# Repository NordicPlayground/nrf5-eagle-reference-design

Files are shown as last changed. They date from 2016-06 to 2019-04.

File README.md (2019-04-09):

# Nordic semiconductor eagle reference design

## Reference designs
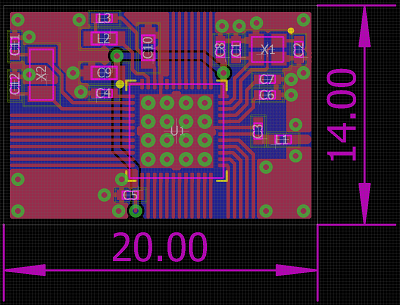
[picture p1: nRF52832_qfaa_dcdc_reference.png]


The reference designs supplied for eagle are made by following the [general pcb design guidelines][designguidenrf52] and referencing the [altium reference layout][altiumreference].
The eagle reference design is not the official reference designs, only the Altium reference designs has been tested and verified. They are available for download in Nordic's product pages.
The reference designs include eagle files as well as pdf printouts. For BOM see the altium reference designs.

* nRF51x22_qfaa
* nRF51x22_qfaa_dcdc
* nRF52832_qfaa
* nRF52832_qfaa_dcdc
* nRF52832_qfaa_nfc

## Libraries
**The libraries are not verified, only the Altium reference designs has been tested and verified.**

### Nordic_nRF
This library contains the nRF51 and nRF52 in qfn and bga packages, as well as; capacitors, inductors, and a 32MHz and 32kHz xtal. All that is needed for the core reference design. (link?)

### Nordic_misc
This library contains the rest of the components used in the sample eagle design(s) in this repository, as well as some simple antenna suggestions.

## Antenna
In the Nordic_misc library there is supplied some suggestions for antennas, please note that antenna characteristics depends greatly on the board layout. These antennas are made according to the [whitepaper][monopole] on quarter wave monopole 2.45 GHz antennas. Remember to [tune][antuning] the antenna

## NFC
An NFC listener antenna suggestion is supplied in the Nordic_misc library, this is the antenna used in the [nRF52-DK] development kit. Remember to [tune][nfctune] the antenna.

[github]: <https://github.com/NordicPlayground/nrf5-eagle-reference-design>
[designguidenrf51]: <https://devzone.nordicsemi.com/blogs/655/general-pcb-design-guidelines-for-nrf51/>
[designguidenrf52]: <https://devzone.nordicsemi.com/blogs/870/general-pcb-design-guidelines-for-nrf52/>
[referencecircuitry]: <https://infocenter.nordicsemi.com/index.jsp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>
[altiumreference]: <http://infocenter.nordicsemi.com/index.jsp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>
[nfctune]: <https://devzone.nordicsemi.com/blogs/957/nfc-tag-antenna-tuning/>
[nRF52-DK]: <http://www.nordicsemi.com/eng/Products/Bluetooth-low-energy2/nRF52-DK>
[dcdc_reference]: <nRF52832_qfaa_dcdc_reference.png>
[monopole]: <http://infocenter.nordicsemi.com/topic/com.nordic.infocenter.whitepapers/dita/whitepapers/pdflinks/nwp_008.html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>
[antuning]: <https://infocenter.nordicsemi.com/topic/com.nordic.infocenter.whitepapers/dita/whitepapers/pdflinks/nwp_017.html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>

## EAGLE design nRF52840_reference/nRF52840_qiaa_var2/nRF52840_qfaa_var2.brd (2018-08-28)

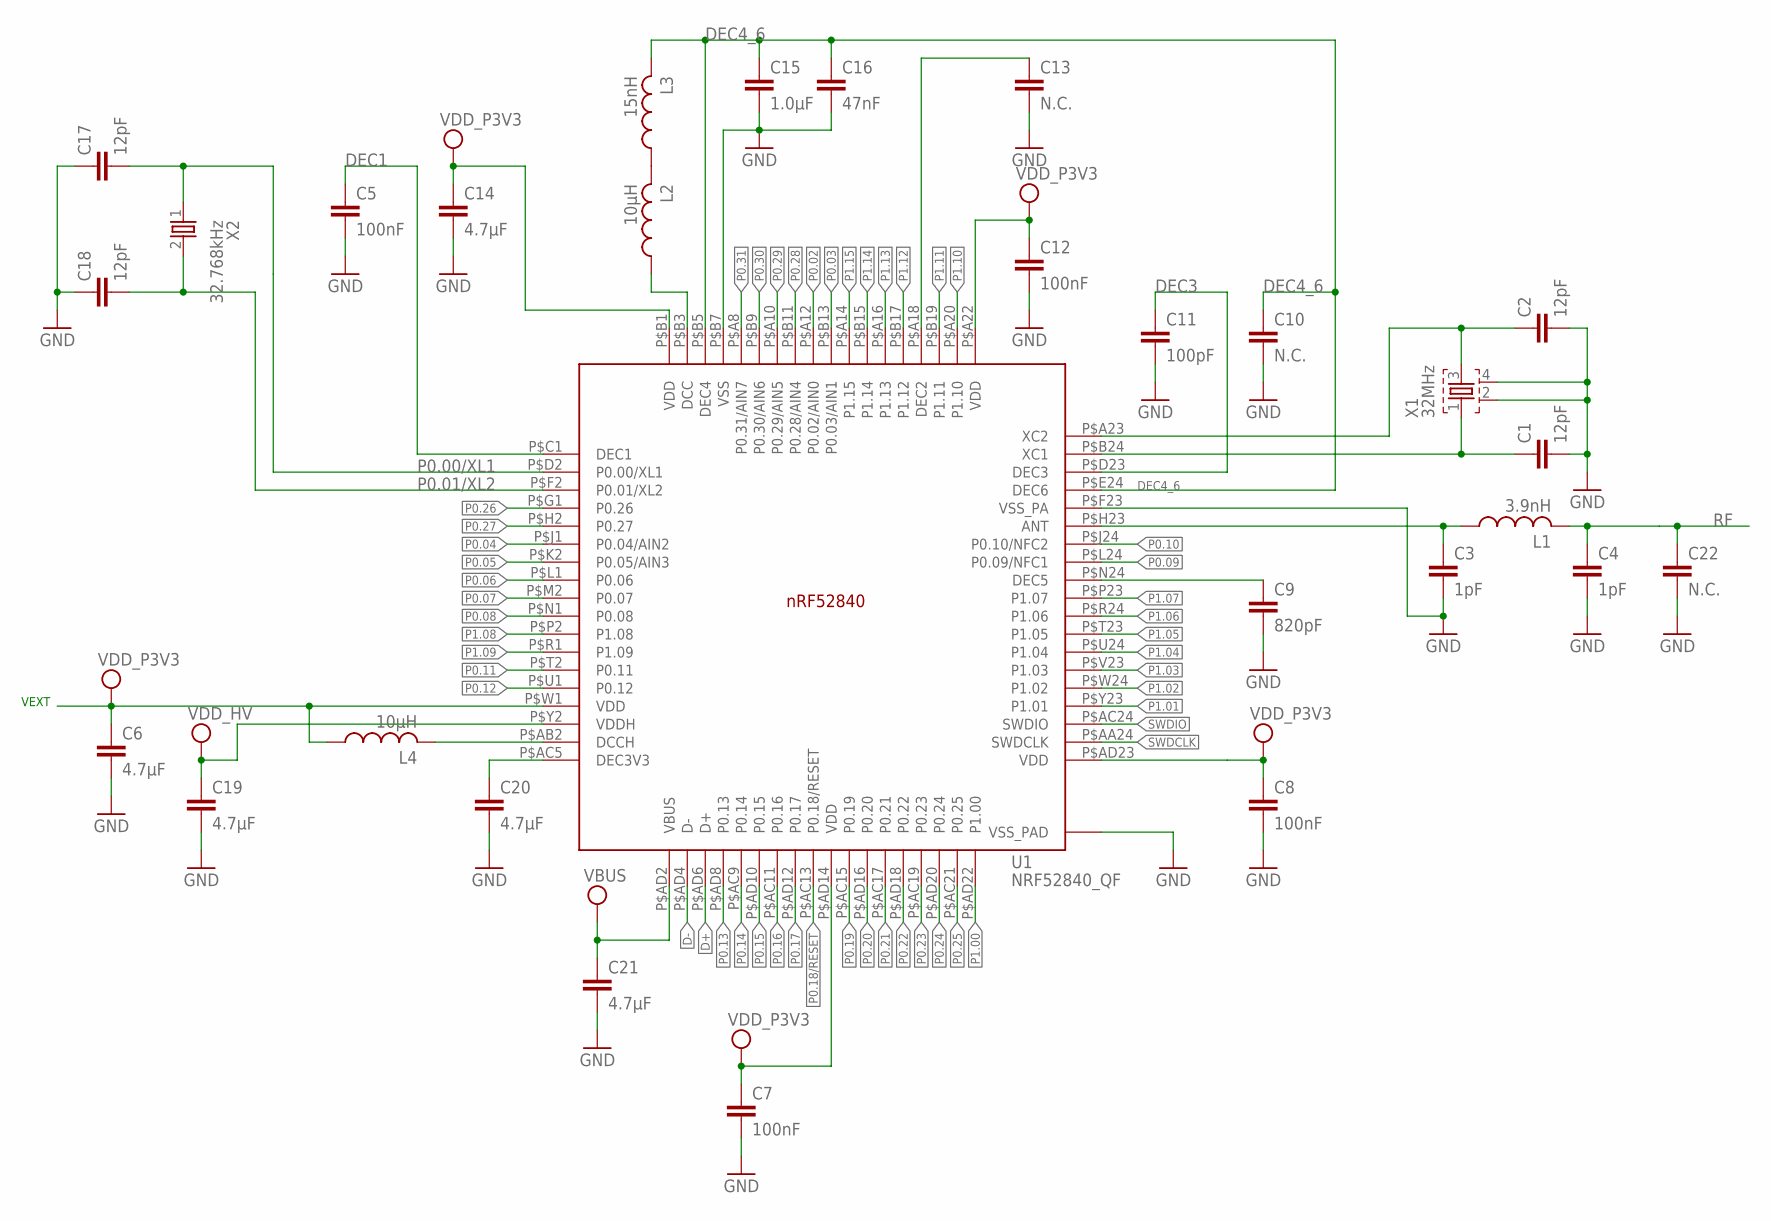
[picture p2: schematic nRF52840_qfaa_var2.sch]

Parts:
C1, C2, C17, C18: 12pF; RESC0402_N
C3, C4: 1pF; RESC0402_N
C5, C7, C8, C12: 100nF; RESC0402_N
C6, C14, C19, C20, C21: 4.7µF; RESC0603_N
C9: 820pF; RESC0402_N
C10, C13, C22: N.C.; RESC0402_N
C11: 100pF; RESC0402_N
C15: 1.0µF; RESC0603_N
C16: 47nF; RESC0402_N
L1: 3.9nH; RESC0402_N
L2, L4: 10µH; RESC0603_N
L3: 15nH; RESC0402_N
U1: NRF52840_QF; AQFN50P700X700X85_HS-74N
X1: 32MHz; BT-XTAL_2016_N
X2: 32.768kHz; XTAL_3215_N

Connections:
ANT: C3.1, L1.1, U1.P$H23 (ANT)
D+: U1.P$AD6 (D+)
D-: U1.P$AD4 (D-)
DCC: L2.1, U1.P$B3 (DCC)
DEC1: C5.1, U1.P$C1 (DEC1)
DEC2: C13.1, U1.P$A18 (DEC2)
DEC3: C11.1, U1.P$D23 (DEC3)
DEC3V3: C20.1, U1.P$AC5 (DEC3V3)
DEC4_6: C10.1, C15.1, C16.1, L3.2, U1.P$B5 (DEC4), U1.P$E24 (DEC6)
DEC5: C9.1, U1.P$N24 (DEC5)
GND: C1.2, C2.2, C3.2, C4.2, C5.2, C6.2, C7.2, C8.2, C9.2, C10.2, C11.2, C12.2, C13.2, C14.2, C15.2, C16.2, C17.1, C18.1, C19.2, C20.2, C21.2, C22.2, U1.P$74 (VSS_PAD), U1.P$75 (VSS_PAD), U1.P$76 (VSS_PAD), U1.P$77 (VSS_PAD), U1.P$78 (VSS_PAD), U1.P$79 (VSS_PAD), U1.P$80 (VSS_PAD), U1.P$81 (VSS_PAD), U1.P$82 (VSS_PAD), U1.P$83 (VSS_PAD), U1.P$84 (VSS_PAD), U1.P$85 (VSS_PAD), U1.P$86 (VSS_PAD), U1.P$87 (VSS_PAD), U1.P$88 (VSS_PAD), U1.P$89 (VSS_PAD), U1.P$90 (VSS_PAD), U1.P$B7 (VSS), U1.P$F23 (VSS_PA), X1.2, X1.4
unnamed: L4.2, U1.P$AB2 (DCCH)
unnamed: L2.2, L3.1
P0.00/XL1: C17.2, U1.P$D2 (P0.00/XL1), X2.1
P0.01/XL2: C18.2, U1.P$F2 (P0.01/XL2), X2.2
P0.02: U1.P$A12 (P0.02/AIN0)
P0.03: U1.P$B13 (P0.03/AIN1)
P0.04: U1.P$J1 (P0.04/AIN2)
P0.05: U1.P$K2 (P0.05/AIN3)
P0.06: U1.P$L1 (P0.06)
P0.07: U1.P$M2 (P0.07)
P0.08: U1.P$N1 (P0.08)
P0.09: U1.P$L24 (P0.09/NFC1)
P0.10: U1.P$J24 (P0.10/NFC2)
P0.11: U1.P$T2 (P0.11)
P0.12: U1.P$U1 (P0.12)
P0.13: U1.P$AD8 (P0.13)
P0.14: U1.P$AC9 (P0.14)
P0.15: U1.P$AD10 (P0.15)
P0.16: U1.P$AC11 (P0.16)
P0.17: U1.P$AD12 (P0.17)
P0.18/RESET: U1.P$AC13 (P0.18/RESET)
P0.19: U1.P$AC15 (P0.19)
P0.20: U1.P$AD16 (P0.20)
P0.21: U1.P$AC17 (P0.21)
P0.22: U1.P$AD18 (P0.22)
P0.23: U1.P$AC19 (P0.23)
P0.24: U1.P$AD20 (P0.24)
P0.25: U1.P$AC21 (P0.25)
P0.26: U1.P$G1 (P0.26)
P0.27: U1.P$H2 (P0.27)
P0.28: U1.P$B11 (P0.28/AIN4)
P0.29: U1.P$A10 (P0.29/AIN5)
P0.30: U1.P$B9 (P0.30/AIN6)
P0.31: U1.P$A8 (P0.31/AIN7)
P1.00: U1.P$AD22 (P1.00)
P1.01: U1.P$Y23 (P1.01)
P1.02: U1.P$W24 (P1.02)
P1.03: U1.P$V23 (P1.03)
P1.04: U1.P$U24 (P1.04)
P1.05: U1.P$T23 (P1.05)
P1.06: U1.P$R24 (P1.06)
P1.07: U1.P$P23 (P1.07)
P1.08: U1.P$P2 (P1.08)
P1.09: U1.P$R1 (P1.09)
P1.10: U1.P$A20 (P1.10)
P1.11: U1.P$B19 (P1.11)
P1.12: U1.P$B17 (P1.12)
P1.13: U1.P$A16 (P1.13)
P1.14: U1.P$B15 (P1.14)
P1.15: U1.P$A14 (P1.15)
RF: C4.1, C22.1, L1.2
SWDCLK: U1.P$AA24 (SWDCLK)
SWDIO: U1.P$AC24 (SWDIO)
VBUS: C21.1, U1.P$AD2 (VBUS)
VDD_HV: C19.1, U1.P$Y2 (VDDH)
VDD_P3V3: C6.1, C7.1, C8.1, C12.1, C14.1, L4.1, U1.P$A22 (VDD), U1.P$AD14 (VDD), U1.P$AD23 (VDD), U1.P$B1 (VDD), U1.P$W1 (VDD)
XC1: C1.1, U1.P$B24 (XC1), X1.1
XC2: C2.1, U1.P$A23 (XC2), X1.3

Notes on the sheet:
VEXT

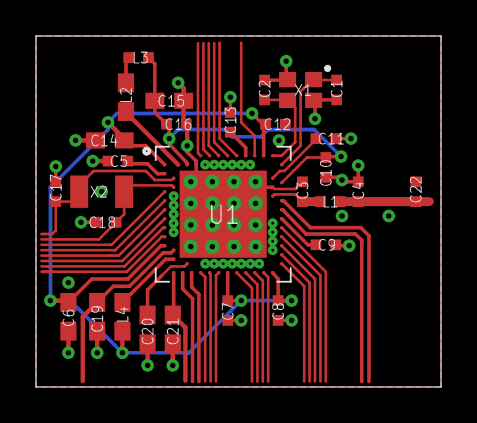
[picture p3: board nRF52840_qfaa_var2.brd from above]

Board: 4 copper layers, 22.5 x 19.5 mm, 29 parts (0 on the bottom side), 19 nets.

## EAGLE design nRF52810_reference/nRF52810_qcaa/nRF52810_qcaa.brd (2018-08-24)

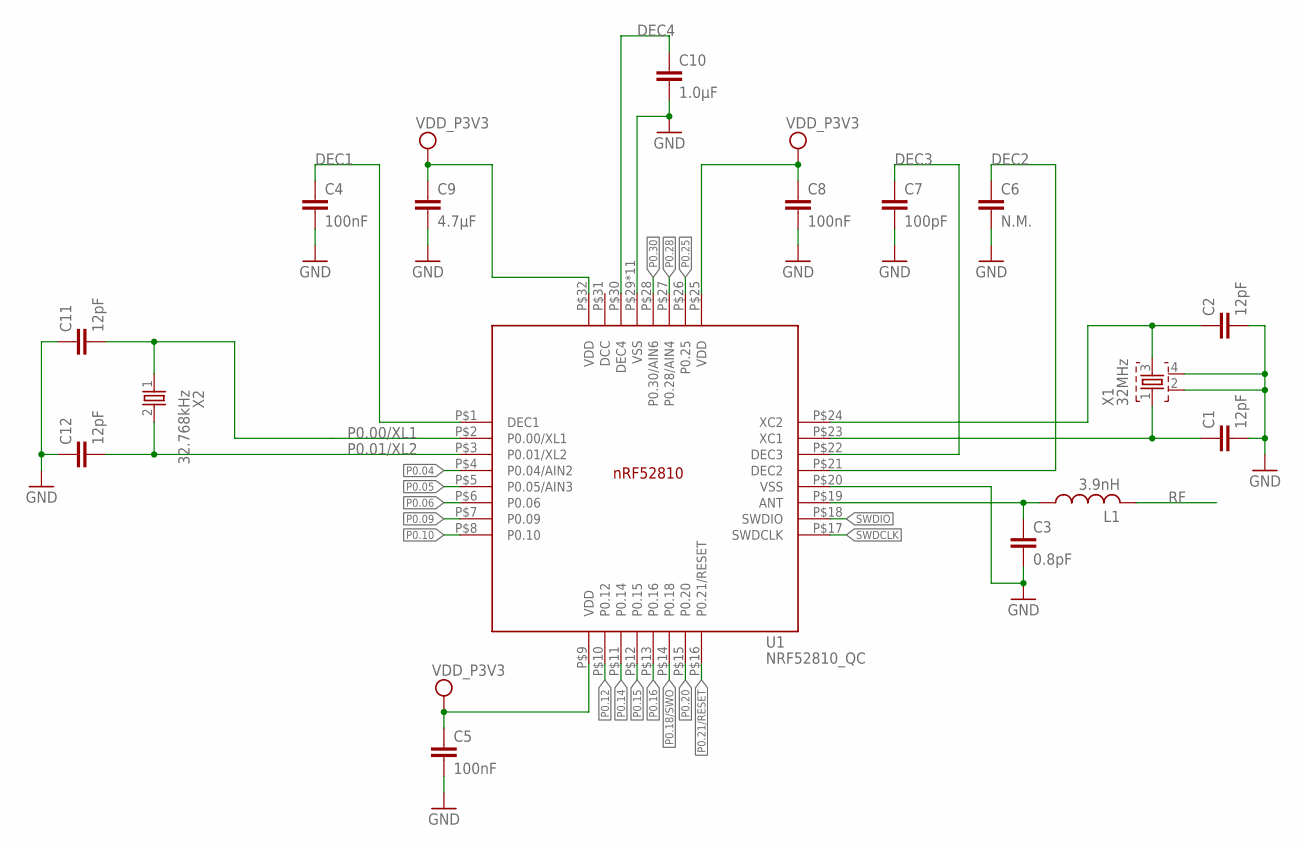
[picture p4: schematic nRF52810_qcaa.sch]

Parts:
C1, C2, C11, C12: 12pF; RESC0402_N
C3: 0.8pF; RESC0402_N
C4, C5, C8: 100nF; RESC0402_N
C6: N.M.; RESC0402_N
C7: 100pF; RESC0402_N
C9: 4.7µF; RESC0603_N
C10: 1.0µF; RESC0603_N
L1: 3.9nH; RESC0402_N
U1: NRF52810_QC; QFN50P500X500X90-32_N
X1: 32MHz; BT-XTAL_2016_N
X2: 32.768kHz; XTAL_3215_N

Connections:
ANT: C3.1, L1.1, U1.P$19 (ANT)
DEC1: C4.1, U1.P$1 (DEC1)
DEC2: C6.1, U1.P$21 (DEC2)
DEC3: C7.1, U1.P$22 (DEC3)
DEC4: C10.1, U1.P$30 (DEC4)
GND: C1.2, C2.2, C3.2, C4.2, C5.2, C6.2, C7.2, C8.2, C9.2, C10.2, C11.1, C12.1, U1.P$20 (VSS), U1.P$29 (VSS), U1.P$33 (VSS), U1.P$34 (VSS), U1.P$35 (VSS), U1.P$36 (VSS), U1.P$37 (VSS), U1.P$38 (VSS), U1.P$39 (VSS), U1.P$40 (VSS), U1.P$41 (VSS), U1.P$42 (VSS), X1.2, X1.4
unnamed: C2.1, U1.P$24 (XC2), X1.3
P0.00/XL1: C11.2, U1.P$2 (P0.00/XL1), X2.1
P0.01/XL2: C12.2, U1.P$3 (P0.01/XL2), X2.2
P0.04: U1.P$4 (P0.04/AIN2)
P0.05: U1.P$5 (P0.05/AIN3)
P0.06: U1.P$6 (P0.06)
P0.09: U1.P$7 (P0.09)
P0.10: U1.P$8 (P0.10)
P0.12: U1.P$10 (P0.12)
P0.14: U1.P$11 (P0.14)
P0.15: U1.P$12 (P0.15)
P0.16: U1.P$13 (P0.16)
P0.18/SWO: U1.P$14 (P0.18)
P0.20: U1.P$15 (P0.20)
P0.21/RESET: U1.P$16 (P0.21/RESET)
P0.25: U1.P$26 (P0.25)
P0.28: U1.P$27 (P0.28/AIN4)
P0.30: U1.P$28 (P0.30/AIN6)
RF: L1.2
SWDCLK: U1.P$17 (SWDCLK)
SWDIO: U1.P$18 (SWDIO)
VDD_P3V3: C5.1, C8.1, C9.1, U1.P$9 (VDD), U1.P$25 (VDD), U1.P$32 (VDD)
X1: C1.1, U1.P$23 (XC1), X1.1

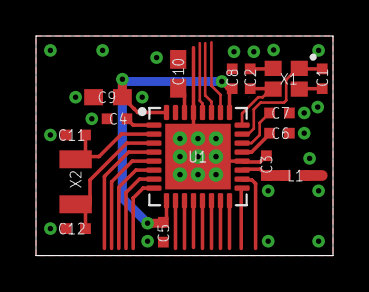
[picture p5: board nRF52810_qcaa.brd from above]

Board: 2 copper layers, 16.5 x 12.2 mm, 16 parts (0 on the bottom side), 11 nets.

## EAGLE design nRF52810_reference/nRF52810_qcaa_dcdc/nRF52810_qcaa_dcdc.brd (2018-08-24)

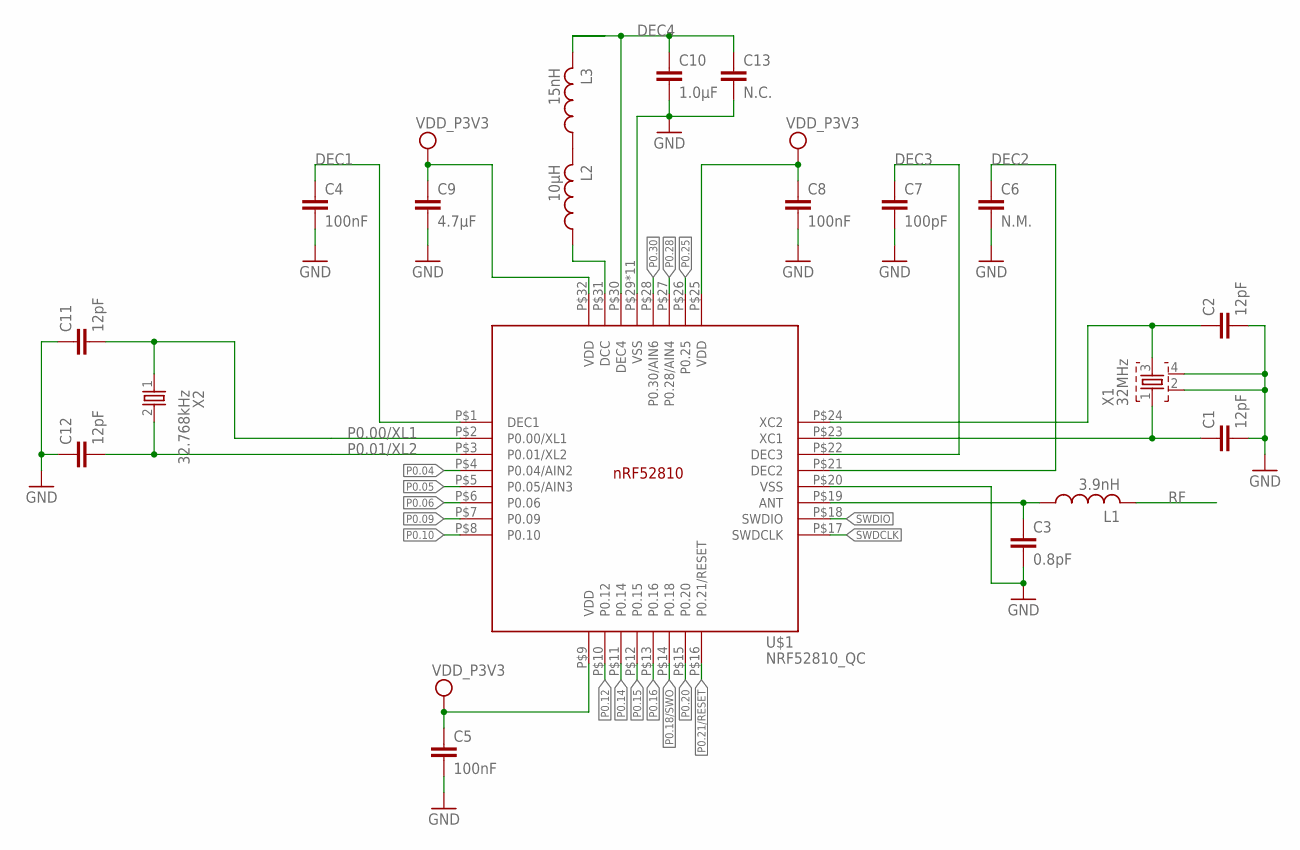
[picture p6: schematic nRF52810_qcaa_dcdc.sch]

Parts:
C1, C2, C11, C12: 12pF; RESC0402_N
C3: 0.8pF; RESC0402_N
C4, C5, C8: 100nF; RESC0402_N
C6: N.M.; RESC0402_N
C7: 100pF; RESC0402_N
C9: 4.7µF; RESC0603_N
C10: 1.0µF; RESC0603_N
C13: N.C.; RESC0402_N
L1: 3.9nH; RESC0402_N
L2: 10µH; RESC0603_N
L3: 15nH; RESC0402_N
U$1: NRF52810_QC; QFN50P500X500X90-32_N
X1: 32MHz; BT-XTAL_2016_N
X2: 32.768kHz; XTAL_3215_N

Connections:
ANT: C3.1, L1.1, U$1.P$19 (ANT)
DEC1: C4.1, U$1.P$1 (DEC1)
DEC2: C6.1, U$1.P$21 (DEC2)
DEC3: C7.1, U$1.P$22 (DEC3)
DEC4: C10.1, C13.1, L3.2, U$1.P$30 (DEC4)
GND: C1.2, C2.2, C3.2, C4.2, C5.2, C6.2, C7.2, C8.2, C9.2, C10.2, C11.1, C12.1, C13.2, U$1.P$20 (VSS), U$1.P$29 (VSS), U$1.P$33 (VSS), U$1.P$34 (VSS), U$1.P$35 (VSS), U$1.P$36 (VSS), U$1.P$37 (VSS), U$1.P$38 (VSS), U$1.P$39 (VSS), U$1.P$40 (VSS), U$1.P$41 (VSS), U$1.P$42 (VSS), X1.2, X1.4
unnamed: L2.2, L3.1
unnamed: C2.1, U$1.P$24 (XC2), X1.3
unnamed: L2.1, U$1.P$31 (DCC)
P0.00/XL1: C11.2, U$1.P$2 (P0.00/XL1), X2.1
P0.01/XL2: C12.2, U$1.P$3 (P0.01/XL2), X2.2
P0.04: U$1.P$4 (P0.04/AIN2)
P0.05: U$1.P$5 (P0.05/AIN3)
P0.06: U$1.P$6 (P0.06)
P0.09: U$1.P$7 (P0.09)
P0.10: U$1.P$8 (P0.10)
P0.12: U$1.P$10 (P0.12)
P0.14: U$1.P$11 (P0.14)
P0.15: U$1.P$12 (P0.15)
P0.16: U$1.P$13 (P0.16)
P0.18/SWO: U$1.P$14 (P0.18)
P0.20: U$1.P$15 (P0.20)
P0.21/RESET: U$1.P$16 (P0.21/RESET)
P0.25: U$1.P$26 (P0.25)
P0.28: U$1.P$27 (P0.28/AIN4)
P0.30: U$1.P$28 (P0.30/AIN6)
RF: L1.2
SWDCLK: U$1.P$17 (SWDCLK)
SWDIO: U$1.P$18 (SWDIO)
VDD_P3V3: C5.1, C8.1, C9.1, U$1.P$9 (VDD), U$1.P$25 (VDD), U$1.P$32 (VDD)
X1: C1.1, U$1.P$23 (XC1), X1.1

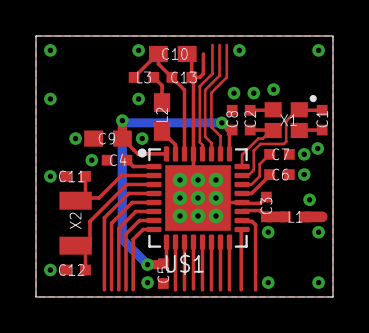
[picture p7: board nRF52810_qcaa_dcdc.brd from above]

Board: 2 copper layers, 16.5 x 14.5 mm, 19 parts (0 on the bottom side), 13 nets.

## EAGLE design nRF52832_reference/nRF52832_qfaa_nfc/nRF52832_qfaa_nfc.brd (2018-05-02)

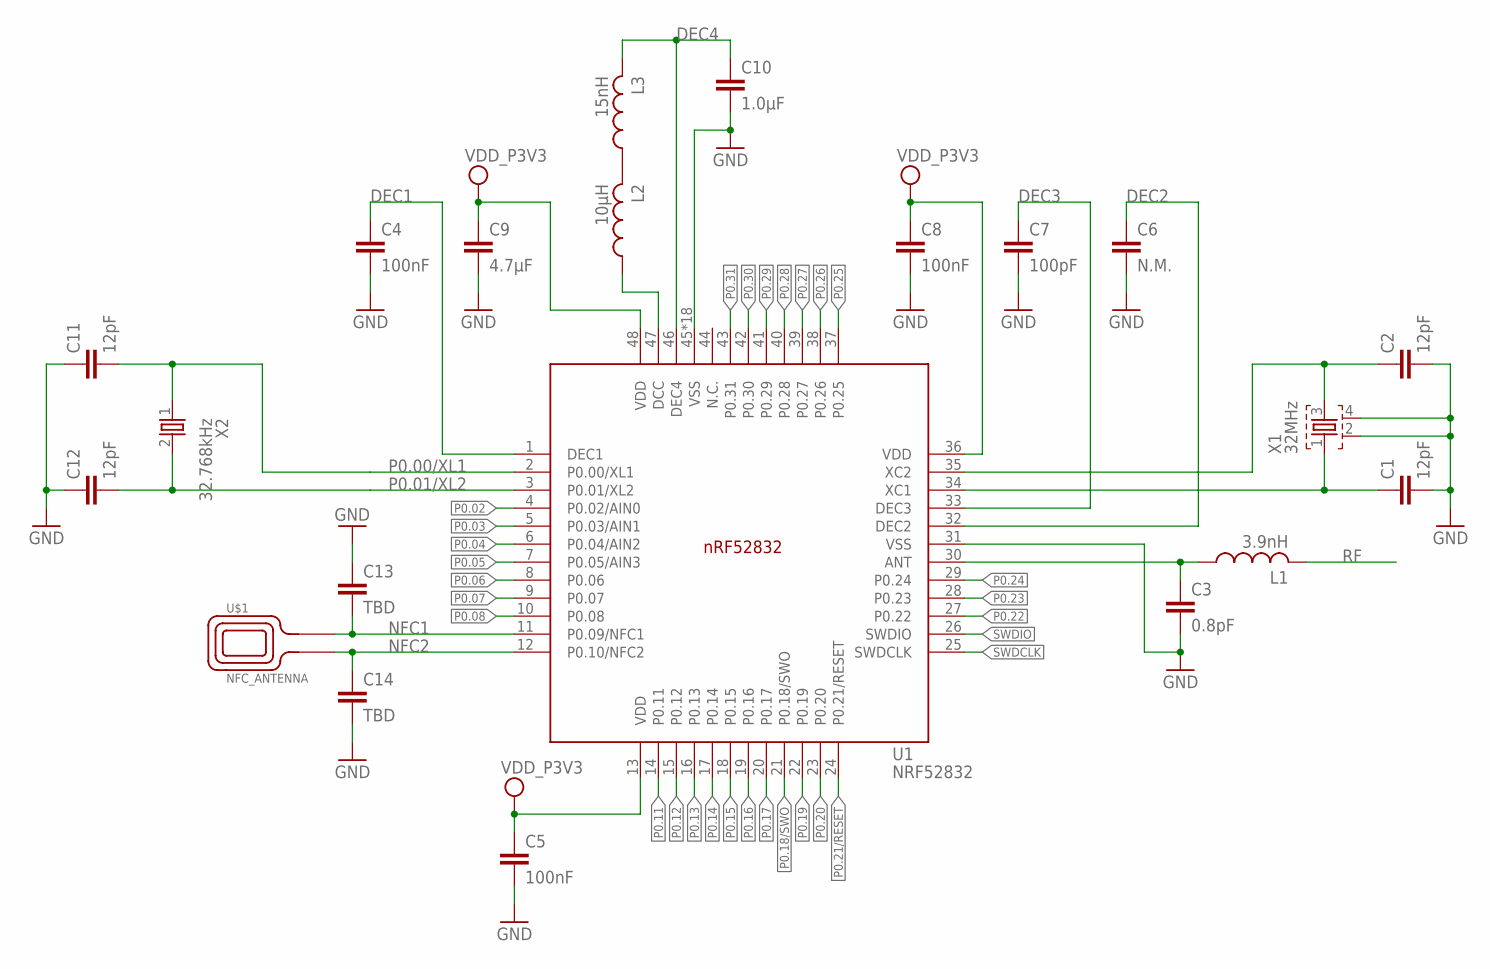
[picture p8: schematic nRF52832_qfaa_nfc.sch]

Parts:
C1, C2, C11, C12: 12pF; RESC0402_N
C3: 0.8pF; RESC0402_N
C4, C5, C8: 100nF; RESC0402_N
C6: N.M.; RESC0402_N
C7: 100pF; RESC0402_N
C9: 4.7µF; RESC0603_N
C10: 1.0µF; RESC0603_N
C13, C14: TBD; RESC0402_N
L1: 3.9nH; RESC0402_N
L2: 10µH; RESC0603_N
L3: 15nH; RESC0402_N
U1: NRF52832; QFN40P600X600X90-48_N
U$1: NFC_ANTENNA; NFC_ANT
X1: 32MHz; BT-XTAL_2016_N
X2: 32.768kHz; XTAL_3215_N

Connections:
ANT: C3.1, L1.1, U1.30 (ANT)
DEC1: C4.1, U1.1 (DEC1)
DEC2: C6.1, U1.32 (DEC2)
DEC3: C7.1, U1.33 (DEC3)
DEC4: C10.1, L3.2, U1.46 (DEC4)
GND: C1.2, C2.2, C3.2, C4.2, C5.2, C6.2, C7.2, C8.2, C9.2, C10.2, C11.1, C12.1, C13.1, C14.2, U1.31 (VSS), U1.45 (VSS), U1.PAD (VSS), U1.PAD@VIA01 (VSS), U1.PAD@VIA02 (VSS), U1.PAD@VIA03 (VSS), U1.PAD@VIA04 (VSS), U1.PAD@VIA05 (VSS), U1.PAD@VIA06 (VSS), U1.PAD@VIA07 (VSS), U1.PAD@VIA08 (VSS), U1.PAD@VIA09 (VSS), U1.PAD@VIA10 (VSS), U1.PAD@VIA11 (VSS), U1.PAD@VIA12 (VSS), U1.PAD@VIA13 (VSS), U1.PAD@VIA14 (VSS), U1.PAD@VIA15 (VSS), U1.PAD@VIA16 (VSS), X1.2, X1.4
unnamed: L2.2, L3.1
unnamed: C2.1, U1.35 (XC2), X1.3
unnamed: L2.1, U1.47 (DCC)
NFC1: C13.2, U1.11 (P0.09/NFC1), U$1.2
NFC2: C14.1, U1.12 (P0.10/NFC2), U$1.1
P0.00/XL1: C11.2, U1.2 (P0.00/XL1), X2.1
P0.01/XL2: C12.2, U1.3 (P0.01/XL2), X2.2
P0.02: U1.4 (P0.02/AIN0)
P0.03: U1.5 (P0.03/AIN1)
P0.04: U1.6 (P0.04/AIN2)
P0.05: U1.7 (P0.05/AIN3)
P0.06: U1.8 (P0.06)
P0.07: U1.9 (P0.07)
P0.08: U1.10 (P0.08)
P0.11: U1.14 (P0.11)
P0.12: U1.15 (P0.12)
P0.13: U1.16 (P0.13)
P0.14: U1.17 (P0.14)
P0.15: U1.18 (P0.15)
P0.16: U1.19 (P0.16)
P0.17: U1.20 (P0.17)
P0.18/SWO: U1.21 (P0.18/SWO)
P0.19: U1.22 (P0.19)
P0.20: U1.23 (P0.20)
P0.21/RESET: U1.24 (P0.21/RESET)
P0.22: U1.27 (P0.22)
P0.23: U1.28 (P0.23)
P0.24: U1.29 (P0.24)
P0.25: U1.37 (P0.25)
P0.26: U1.38 (P0.26)
P0.27: U1.39 (P0.27)
P0.28: U1.40 (P0.28)
P0.29: U1.41 (P0.29)
P0.30: U1.42 (P0.30)
P0.31: U1.43 (P0.31)
RF: L1.2
SWDCLK: U1.25 (SWDCLK)
SWDIO: U1.26 (SWDIO)
VDD_P3V3: C5.1, C8.1, C9.1, U1.13 (VDD), U1.36 (VDD), U1.48 (VDD)
X1: C1.1, U1.34 (XC1), X1.1

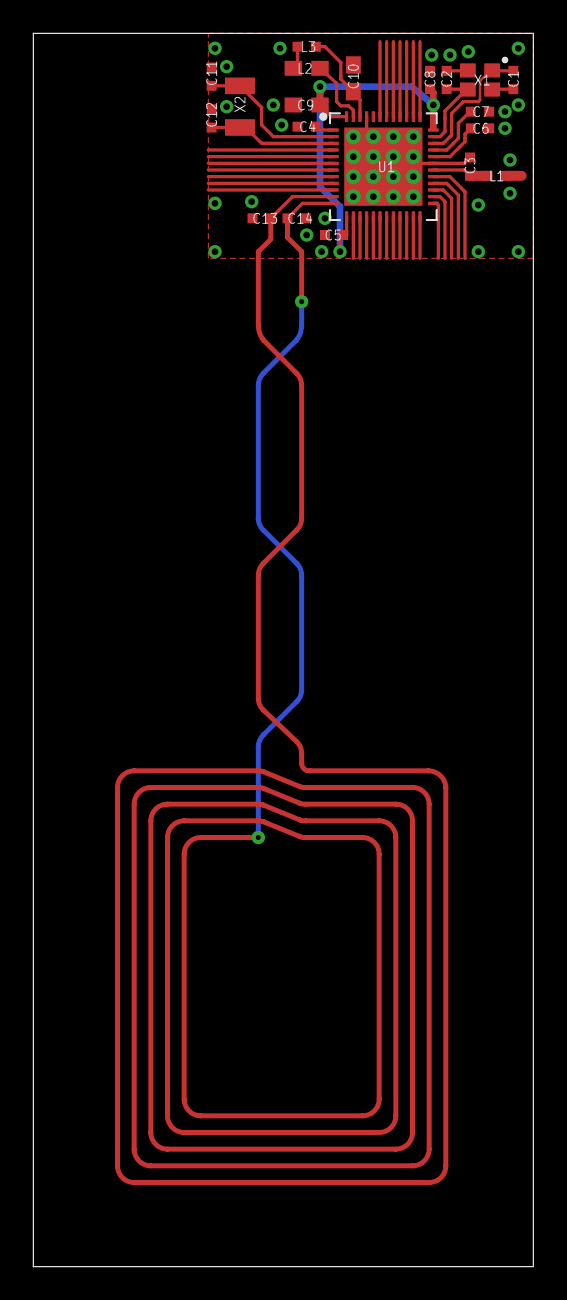
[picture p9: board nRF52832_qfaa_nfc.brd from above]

Board: 2 copper layers, 30.0 x 74.0 mm, 21 parts (0 on the bottom side), 15 nets.

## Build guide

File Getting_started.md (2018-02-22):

# Getting started with nRF5 and CadSoft EAGLE (R)

Nordic Semiconductor already provides [reference designs][altiumreference] for Altium Designer (R), but if you prefer EAGLE here is a quick guide on how to use the EAGLE reference design.

This quick guide assumes you are familiar with doing PCB designs in EAGLE, otherwise both [Adafruit] and [SparkFun] have guides on how to get started.

1. First clone or download the reference designs and libraries from [Github]
2. Select the reference-design that fits your application (if you are uncertain use *nRF52832_qfaa_dcdc*)
3. Add your own parts in the circuit diagram
4. Create the layout and routing
	* Do not modify the geometry of the rf part

Please refer to the general pcb design guidelines for [nRF51][designguidenrf51] or [nRF52][designguidenrf52].

### 1. First clone or download the reference designs and libraries from [Github]

If you are familiar with [git] this is self explanatory, if not press the (green) "Clone or download" button and then "Download ZIP".

### 2. Select the reference-design that fits your application

All reference designs supplied here are for the QFN package.
If you want to use the internal ldo (not recommended) select nRF5\*_qfaa, if you want an example of nfc antenna usage select nRF5\*_qfaa_nfc.
You probably want the nRF51x2_qfaa_dcdc or nRF52832_qfaa_dcdc, for nRF51 or nRF52 respectively.

### 3. Add your own parts in the circuit diagram

Here is the part where you do your design, use your own libraries, use libraries supplied with eagle, use parts from the Nordic_misc library, make your own parts, etc.

### 4. Do the layout and routing

This is also a part of your regular workflow. Lay out your design next to or around the reference layout.

#### Do not modify the geometry of the rf part

Now, the important part: Do not add components close to the rf layout. This means around where you attach the antenna (the signal named RF).
The cutout in the ground plane is there for a reason. Add cutouts to any internal layers of the pcb as well. There should be a ground plane on the bottom layer.
Add a generous amount of ground stiching vias (remember vias are free).

### 5. Done

There. You are done with your nRF5 design in eagle, dont forget to run design reviews before ordering pcbs. And dont forget to tune the antenna when you have your prototype in hand.

# Some info on the git repository

## Reference designs


The reference designs supplied for eagle are made by following the [general pcb design guidelines][designguidenrf52] and referencing the [altium reference layout][altiumreference].
The reference designs include eagle files as well as pdf printouts. For BOM see the altium reference designs.

* nRF51x22_qfaa
* nRF51x22_qfaa_dcdc
* nRF52832_qfaa
* nRF52832_qfaa_dcdc
* nRF52832_qfaa_nfc

## Libraries

### Nordic_nRF
This library contains the nRF51 and nRF52 in QFN and bga packages, as well as; capacitors, inductors, and a 32MHz and 32kHz xtal. All that is needed for the core reference design.

### Nordic_misc
This library contains the rest of the components used in the sample eagle design(s) in the github repository, as well as some simple antenna suggestions.

## Antenna
In the Nordic_misc library there is supplied some suggestions for antennas, please note that antenna characteristics depends greatly on the board layout. These antennas are made according to the [whitepaper][monopole] on quarter wave monopole 2.45 GHz antennas. Remember to [tune][antuning] the antenna.

## NFC
An NFC listener antenna suggestion is supplied in the Nordic_misc library, this is the antenna used in the [nRF52-DK] development kit. Remember to [tune][nfctune] the antenna.

[sparkfun]: <https://www.sparkfun.com/>
[adafruit]: <https://www.adafruit.com/>
[github]: <https://github.com/NordicPlayground/nrf5-eagle-reference-design>
[designguidenrf51]: <https://devzone.nordicsemi.com/blogs/655/general-pcb-design-guidelines-for-nrf51/>
[designguidenrf52]: <https://devzone.nordicsemi.com/blogs/870/general-pcb-design-guidelines-for-nrf52/>
[referencecircuitry]: <https://infocenter.nordicsemi.com/index.jsp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>
[altiumreference]: <http://infocenter.nordicsemi.com/index.jsp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>
[nfctune]: <https://devzone.nordicsemi.com/blogs/957/nfc-tag-antenna-tuning/>
[nRF52-DK]: <http://www.nordicsemi.com/eng/Products/Bluetooth-low-energy2/nRF52-DK>
[dcdc_reference]: <nRF52832_qfaa_dcdc_reference.png>
[monopole]: <http://infocenter.nordicsemi.com/topic/com.nordic.infocenter.whitepapers/dita/whitepapers/pdflinks/nwp_008.html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>
[antuning]: <https://infocenter.nordicsemi.com/topic/com.nordic.infocenter.whitepapers/dita/whitepapers/pdflinks/nwp_017.html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>
[git]: <https://git-scm.com/>

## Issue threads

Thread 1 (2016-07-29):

Please add nRF52832 CSP package

hnhoan, 2016-07-29:

Cable89, 2016-08-01:
Done,
Found as NRF52832_CI
please give feedback if you find any errors.

Closed 2016-08-01.

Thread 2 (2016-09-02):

nRF52832_qfaa_dcdc.sch incorrectly lists C7 as 100nf

jacobrosenthal, 2016-09-02:
In nRF52832_qfaa_dcdc.sch (and maybe others?) C7 is I believe incorrectly listed as 100nF as the nrf52832_qfaa_dcdc_bom.xls in the reference http://infocenter.nordicsemi.com/index.jsp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 lists C7 as 100pF

Cable89, 2016-09-06:
You are correct, thank you for pointing it out. I changed the value of C7 to 100pF in the schematics for all three nrf52 schematics.

Closed 2016-09-06.

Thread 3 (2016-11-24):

DEBUG_CONNECTOR - wrong connection P0.21/RESET - 6 and P0.18/SWO - 10 ??

BrunoArgon18, 2016-11-24:
Hi. i would like to know if the connection between P0.21/RESET - 6 and P0.18/SWO - 10  are correct.

I checked this document (PCA10040_Schematic_And_PCB.pdf) and they say that:

P0.21/RESET - 10 and P0.18/SWO - 6

There is the http://infocenter.arm.com/help/topic/com.arm.doc.faqs/attached/13634/cortex_debug_connectors.pdf

from ARM that say the same thing.

Tks

Cable89, 2016-12-01:
You are correct, P0.21 should be connected to 10 and P0.18 to 6.
However you will still be able to debug as it is only SWDIO and SWDCLK wich are used during debugging. If reset is not present it will do a soft reset.

Thank you, it should be correct now.

Closed 2016-12-01.

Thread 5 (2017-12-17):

Mislabeled nRF52840 DEC6 Pin

Nikg92, 2017-12-17:
For the schematic part on the nRF52840 IC the pin DEC6 is mislabeled DEC2.

Cable89, 2018-04-06:
You are correct, thanks for catching it.

Closed 2018-04-06.

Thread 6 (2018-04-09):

Mislabeled NFC pin?

todeschini-felipe, 2018-04-09:
Surely those are minor "issues", but I wanted to inquire about them (and give some "contribution") to ensure **nRF52832_qfaa_dcdc schematic** consistency with **nRF52832 Product Specification v 1.4 pg. 546 **.

1. I believe that P0.09 and P0.10 are mislabeled as P0.01 and P0.09, respectively.
2. Capacitor C1 and C2 labels seem to be inverted.

I believe, nonetheless, that these things do not actually change the schematic "behavior".
Regards,

Cable89, 2018-05-02:
Hi,
Thanks for the feedback. Even minor stuff like this may cause unnecessary confusion.

1. Fixed.
2. Swapped them.

Closed 2018-05-02.

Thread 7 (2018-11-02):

Warning: line 7: unknown attribute 'keepoldvectorfont' in tag <setting>

kapilsinghrawat, 2018-11-02:
Hi
I'm using eagle 5.6 Version.
While adding component I'm getting below warning

[Warning.txt](https://github.com/NordicPlayground/nrf5-eagle-reference-design/files/2543920/Warning.txt)

Could you please check this issue.

Cable89, 2018-11-07:
It seems this is a compatibility issue as the library was last saved from version 8.3.0.
If you are not using the newest parts, you could try checking out an earlier version of this repo.
Or since it is just a warning you could ignore it. From the name of the warning it does not seem to be an issue, just a new tag used for backwards compatibility in newer versions.

Closed 2018-11-13.

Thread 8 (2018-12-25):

nrf52840 refrerences show nrf52830

rsaxvc, 2018-12-25:
All PDFs in https://github.com/NordicPlayground/nrf5-eagle-reference-design/tree/master/nRF52840_reference show nRF52832 instead of nRF52840. Example: https://github.com/NordicPlayground/nrf5-eagle-reference-design/blob/master/nRF52840_reference/nRF52840_qiaa_var1/nRF52840_qfaa_var1_sch.pdf

Cable89, 2019-04-09:
Thanks, it seems I have forgotten to generate the pdfs for the nRF52840, and the old pdfs from nRF52832 has remained. I have now generated the correct pdfs.

Closed 2019-04-09.

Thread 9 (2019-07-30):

nRF52840 reference designs 2 - 6 are incorrect

strangesast, 2019-07-30:
Reference nRF52840 pcb schematics and layouts are exactly the same for examples 2-6.  I believe each is a copy of var4.  The schematics for these reference designs are listed correctly in  the specification document but do not match what is included here.

shas for the files mentioned:
**33e3b6ec2ab9c637af923696b05402c14a7aad5f  ./nRF52840_qiaa_var4/nRF52840_qfaa_var4.brd
33e3b6ec2ab9c637af923696b05402c14a7aad5f  ./nRF52840_qiaa_var3/nRF52840_qfaa_var3.brd
33e3b6ec2ab9c637af923696b05402c14a7aad5f  ./nRF52840_qiaa_var6/nRF52840_qfaa_var6.brd
33e3b6ec2ab9c637af923696b05402c14a7aad5f  ./nRF52840_qiaa_var5/nRF52840_qfaa_var5.brd
33e3b6ec2ab9c637af923696b05402c14a7aad5f  ./nRF52840_qiaa_var2/nRF52840_qfaa_var2.brd**
5277508d2408c335e8cf7c6b7b72fe56d11456ea  ./nRF52840_qiaa_var1/nRF52840_qfaa_var1.brd

**33e3b6ec2ab9c637af923696b05402c14a7aad5f  ./nRF52840_qiaa_var4/nRF52840_qfaa_var4.brd
33e3b6ec2ab9c637af923696b05402c14a7aad5f  ./nRF52840_qiaa_var3/nRF52840_qfaa_var3.brd
33e3b6ec2ab9c637af923696b05402c14a7aad5f  ./nRF52840_qiaa_var6/nRF52840_qfaa_var6.brd
33e3b6ec2ab9c637af923696b05402c14a7aad5f  ./nRF52840_qiaa_var5/nRF52840_qfaa_var5.brd
33e3b6ec2ab9c637af923696b05402c14a7aad5f  ./nRF52840_qiaa_var2/nRF52840_qfaa_var2.brd**
5277508d2408c335e8cf7c6b7b72fe56d11456ea  ./nRF52840_qiaa_var1/nRF52840_qfaa_var1.brd

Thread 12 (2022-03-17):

NRF52840-QF has incorrect name

jonnerd154, 2022-03-17:
According to the NRF52840 datasheet (https://infocenter.nordicsemi.com/pdf/nRF52840_PS_v1.7.pdf) page 627 (Table 187: Package variant codes), the `-QF` variant is a 48-pin 6x6mm 0.4mm pitch QFN package.

The library part called `NRF52840-QF` is actually `NRF52840-QI` - the 73pin aQFN variant, not the 48-pin QFN.

jonnerd154, 2022-03-17:
Addressed in PR #13.

Closed 2022-03-22.

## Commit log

2016-06-15 Finished? footprint and symbol for nRF5, QFN. Done som experimenting on board layouts
    [nRF52832_MCU.brd, nRF52832_MCU.sch]
2016-06-15 Changd layer of silkscreen
2016-06-15 Fixed chip components(resistors) Moved physical outline to tDocu layer
2016-06-16 Added antennas, added passive components
2016-06-16 Fixed paste, and soldermask layers in antennas
2016-06-16 Fixed silkscreen on meander antenna
2016-06-17 Moved resistor value inside resistor
2016-06-20 Routed gpio
    [nRF52832_MCU.brd, nRF52832_MCU.sch]
2016-06-21 Added switches
2016-06-21 Positioned buttons, positioned powersupply
    [nRF52832_MCU.brd, nRF52832_MCU.sch]
2016-06-21 Removed all non-library files (not ready for publishing)
    [nRF52832_MCU.brd, nRF52832_MCU.sch]
2016-06-21 Readded nRF52832_MCU_Board
    [nRF52832_MCU.brd, nRF52832_MCU.sch]
2016-06-21 Fixed library links
    [nRF52832_MCU.brd, nRF52832_MCU.sch]
2016-06-21 Added LED
2016-06-21 Done some layout
    [nRF52832_MCU.brd, nRF52832_MCU.sch]
2016-06-21 Squezed in nfc antenna connector
    [nRF52832_MCU.brd]
2016-06-21 Connected all signals in layout
    [nRF52832_MCU.brd, nRF52832_MCU.sch]
2016-06-21 Copyed layout from nano to arduino
    [nRF52832_MCU.brd, nRF52832_MCU.sch]
2016-06-22 Copied altium reference designs
    [nRF52832_qfaa.brd, nRF52832_qfaa.sch, nRF52832_qfaa_dcdc.brd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]
2016-06-22 Added more vias
    [nRF52832_qfaa.brd, nRF52832_qfaa_dcdc.brd, nRF52832_qfaa_nfc.brd]
2016-06-22 Added NFC antenna
2016-06-22 Looked at arduino layout
    [nRF52832_MCU.brd]
2016-06-23 Copied reference layout from altium
    [nRF51x22_qfaa_dcdc.brd, nRF51x22_qfaa_dcdc.sch]
2016-06-23 Removed old files
    [nRF52832_MCU.brd, nRF52832_MCU.sch]
2016-06-23 Cleanup in layout
    [nRF52832_MCU.brd, nRF52832_MCU.sch]
2016-06-23 Added some vias
    [nRF52832_MCU.brd, nRF52832_MCU.sch]
2016-06-23 Cleaned up schematic
    [nRF52832_MCU.brd, nRF52832_MCU.sch]
2016-06-23 Looked into different layout
    [nRF52832_MCU.brd, nRF52832_MCU.sch]
2016-06-28 Restructured MCU_Board
    [nRF52832_MCU.brd, nRF52832_MCU.sch]
2016-06-28 Regenerated pdfs with polygons pured
    [nRF51x22_qfaa.brd]
2016-06-30 Updated silk on some components, fixed via clearance at NFC and decoupling, fixed clearance at batt, routed XL1 and XL2, tented vias
    [nRF52832_MCU.brd, nRF52832_MCU.sch]
2016-06-30 Done some work in silk
    [nRF52832_MCU.brd, nRF52832_MCU.sch]
2016-07-04 Added more vias, fixed error in silkscreen at J1
    [nRF52832_MCU.brd]
2016-07-04 Added name to headers in library, named headers properly
    [nRF52832_MCU.brd, nRF52832_MCU.sch]
2016-07-04 Ran DRC, approved errors
    [nRF52832_MCU.brd]
2016-07-08 Moved copper plane away from antenna connection point
    [nRF52832_MCU.brd]
2016-07-11 Generated gerber
    [nRF52832_MCU.GBL, nRF52832_MCU.GBO, nRF52832_MCU.GBS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]
2016-09-06 Issue #2: Fixed value of C7 from 100nF to 100pF
    [nRF52832_qfaa.brd, nRF52832_qfaa.sch, nRF52832_qfaa_dcdc.brd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]
2016-12-01 Issue #3: Fixed wrong connections on P0.21/RESET - 6 and P0.18/SWO - 10
    [nRF52832_MCU.brd, nRF52832_MCU.sch]
2018-04-06 Mislabeled nRF52840 DEC6 Pin, closes #5
2018-05-02 Small label/designator update, fixes #6
    [nRF52832_qfaa_dcdc.brd, nRF52832_qfaa_dcdc.sch]
2018-05-02 Same fixes as in qfaa_dcdc
    [nRF52832_qfaa.brd, nRF52832_qfaa.sch, nRF52832_qfaa_nfc.brd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]
2018-08-23 Removed 'nRF52832_MCU-board'
    [nRF52832_MCU.brd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]
2018-08-23 Resized nRF52810 schematic symbol to same size as nRF52832, also renamed to the proper Packet variant name
2018-08-23 Added nRF52810_qfaa reference layout (copied from nRF52832_qfaa, pin compatible)
    [nRF52810_qfaa.brd, nRF52810_qfaa.sch, nRF52810_qfaa_dcdc.brd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]
2018-08-23 Eagle did not save properly
    [nRF52810_qfaa_dcdc.brd, nRF52810_qfaa_dcdc.sch]
2018-08-24 Added nRF52810_qcaa reference
    [nRF52810_qcaa.brd, nRF52810_qcaa.sch, nRF52810_qcaa_dcdc.brd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]
2018-08-28 Started nRF52840 reference layout
    [nRF52840_qfaa_var1.brd, nRF52840_qfaa_var1.sch, nRF52840_qfaa_var2.brd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]
